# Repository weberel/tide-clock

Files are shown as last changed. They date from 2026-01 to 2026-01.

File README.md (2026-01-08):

# Tide Clock

A battery-powered e-paper display showing tide times. Configurable for any coastal location. This device does not need an internet or bluetooth connection as all data is calculated on the device itself from a given time and location. Thanks to the display type and slow refreshrate with long sleep cycles this device can operate on two AA-batteries for at least 3 years.

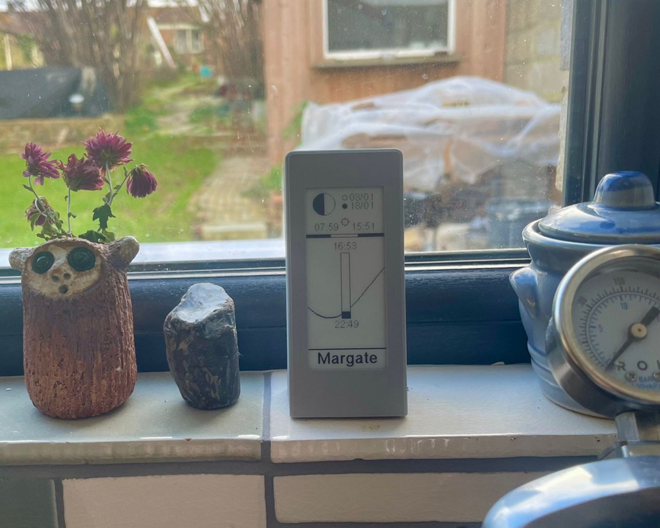
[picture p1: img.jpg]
Tide Clock


## Features

- **Tide prediction** - Next high/low tide times using a 31-constituent harmonic model
- **Moon phase** - Current phase with upcoming full/new moon dates
- **Sunrise/Sunset** - Daily times with 24-hour daylight visualization bar
- **Special messages** - Solstices, equinoxes, eclipses, meteor showers, holidays
- **Offline operation** - Pure mathematical models, no internet required
- **Multi-year battery life** - 15-minute wake cycles with deep sleep between updates

## Hardware

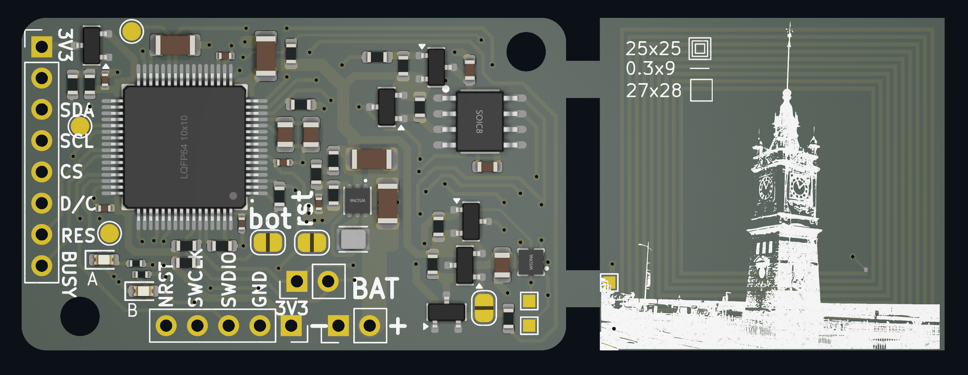
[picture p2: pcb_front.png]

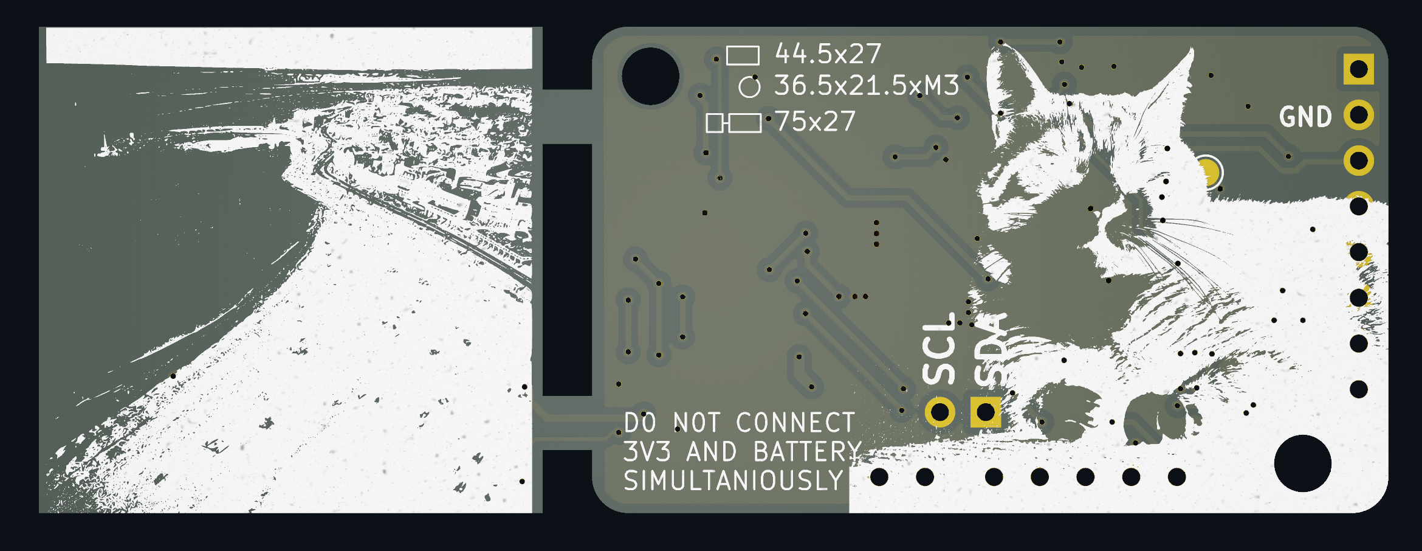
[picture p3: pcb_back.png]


- **MCU**: STM32F411RET6 (ARM Cortex-M4)
- **Display**: 2.9" e-paper (296x128, SSD1680 controller)
- **RTC**: DS3231MZ+ with alarm wake
- **Power**: AA batteries with TPS61099 boost converter

## Project Structure

```
tidal-clock/
├── firmware/          # STM32 firmware (Rev A & B)
├── simulator/         # SDL2 simulator for testing
├── scripts/           # Location config generation
│   └── harmonic_fitting/  # Tide model fitting
├── kicad/             # PCB designs
└── manual/            # User manual
```

Each folder has its own README with detailed instructions.

## Quick Start

### Simulator

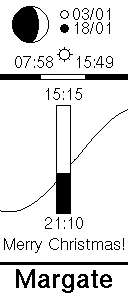
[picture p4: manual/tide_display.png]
Tide Display


```bash
cd simulator
sudo apt install libsdl2-dev
git clone https://github.com/olikraus/u8g2.git
make && ./tide_sim
```

### Firmware

```bash
cd firmware/revA  # or revB
cd lib && git clone https://github.com/olikraus/u8g2.git && cd ..
pio run --target upload
```

## Customizing Location

Configure for any coastal location. See [scripts/README.md](scripts/README.md) for details.

**US locations** (using NOAA API):
```bash
cd scripts
python3 generate_location.py --noaa 9414290 --name "San Francisco" --tz US_PACIFIC
```

**Other locations** (fit your own model):
```bash
python3 generate_location.py --json harmonic_fitting/model.json --name "Location" --tz UK
```

## License

MIT

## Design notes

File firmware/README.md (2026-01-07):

# Firmware

STM32 firmware for the tide clock. Two hardware revisions are supported.

## Building

```bash
# For Rev A hardware
cd revA
cd lib && git clone https://github.com/olikraus/u8g2.git && cd ..
pio run
pio run --target upload  # via ST-Link

# For Rev B hardware
cd revB
cd lib && git clone https://github.com/olikraus/u8g2.git && cd ..
pio run
pio run --target upload
```

## Configuration

Location settings are in `include/location_config.h`. Generate with:

```bash
cd scripts
python3 generate_location.py --noaa 9414290 --name "San Francisco" --tz US_PACIFIC
```

See the scripts README for more options.

## Hardware Differences

See [kicad/versions.md](../kicad/versions.md) for differences between Rev A and Rev B.

## Key Files

| File | Description |
|---|---|
| `src/main.c` | Entry point, power management |
| `src/tide.c` | Harmonic tide prediction |
| `src/astro.c` | Moon phase, sunrise/sunset |
| `src/timezone.c` | DST handling |
| `src/render.c` | Display layout |
| `include/location_config.h` | Location parameters (generated) |

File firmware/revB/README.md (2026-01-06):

# Tide Display - STM32 Hardware (Rev B)

E-paper tide display for Margate, UK using STM32F411CE and 2.9" SSD1680 tri-color display.

**This is the Rev B firmware.** See [firmware-revA](../firmware-revA/) for Rev A hardware.

## Hardware Changes (Rev B)

| Feature | Rev A | Rev B |
|---|---|---|
| NFC chip | NT3H2111 (unused) | ST25DV04K (for time sync) |
| Time setting | Button on PB1 | NFC (phone app) |
| PA2 function | NT3H2111 power gate | NFC LPD control |
| Button | PB1 (active LOW) | Removed |
| Wakeup | RTC alarm only | RTC alarm OR NFC field |
| External power | None | PB9 (3V3 gated output) |

## Features

- Current tide height with visual bar indicator
- Next high/low tide times (31-constituent harmonic model, ~5 min accuracy)
- Sunrise/sunset times with daylight bar
- Moon phase with next full/new moon dates
- Automatic BST/GMT timezone handling for UK
- 15-minute update cycle with deep sleep (~µA standby current)
- NFC time synchronization (planned)

## Operation

The device wakes from two sources:
1. **RTC alarm** (every 15 minutes) - normal display update
2. **NFC field** (phone tap) - time synchronization

Wake cycle:
1. PA0 rising edge wakes MCU from STOP mode
2. Determine wake source (check DS3231 alarm flag vs ST25DV field detect)
3. If NFC: read time sync data, update RTC if valid
4. If RTC alarm: update display
5. Set next alarm, enter STOP mode

## Building & Uploading

Requires PlatformIO.

```bash
# Build
pio run

# Upload via ST-Link
pio run --target upload
```

**Note:** If upload fails due to device in sleep mode, hold RESET while plugging in ST-Link, then release when upload starts.

## RTC Time Setting (Rev B)

Time is set via NFC:
1. Phone app writes time data to ST25DV user memory
2. Tapping phone to device wakes MCU via GPO → PA0
3. MCU reads time data, validates checksum
4. Updates DS3231 RTC
5. Display confirms sync (TODO)

See [kicad/versions.md](../../kicad/versions.md) for NFC time sync protocol details.

## Project Structure

```
firmware-revB/
├── src/
│   ├── main.c              # Entry point, RTC, NFC, sleep/wake cycle
│   ├── st25dv.c            # ST25DV04K NFC driver
│   ├── display_u8g2_stm32.c # Display HAL backend (SPI, GPIO)
│   ├── render.c            # UI rendering (layout, icons)
│   ├── tide.c              # Tide calculations (31-harmonic model)
│   ├── astro.c             # Sun/moon calculations (Meeus/NOAA)
│   └── timezone.c          # UK timezone handling (GMT/BST)
├── include/
│   ├── st25dv.h            # ST25DV04K driver header
│   └── *.h                 # Other headers
├── lib/
│   └── u8g2/               # u8g2 graphics library + custom SSD1680 driver
└── platformio.ini
```

## Pin Configuration (Rev B)

| Pin | Function |
|-----|---|
| PA0 | Wakeup (OR'd: RTC alarm + NFC field) |
| PA1 | DS3231 VCC gate (P-FET, active LOW) |
| PA2 | ST25DV LPD (HIGH = low power) |
| PA3 | Display VCC gate (P-FET, active LOW) |
| PB3 | Debug output (SWO) |
| PB6/PB7 | I2C1 (DS3231 + ST25DV) |
| PB9 | External 3V3 gate (P-FET, active LOW) |
| PC11 | LED2 |
| PD2 | LED1 |

## TODO

- [ ] Implement NFC time sync in main loop
- [ ] Add display confirmation after time sync
- [ ] Test wakeup from NFC field detection
- [ ] Implement external power control (PB9)

---

# Rendering System Report

## Overview

The rendering system produces a 128x296 pixel display showing tide, sun, and moon information for Margate, UK. The display is rotated 90 degrees for a portrait orientation.

## Display Layout

```
┌─────────────────────────────────────┐
│  ┌───┐                              │
│  │   │ Moon    ○ 15/01  (full)      │  Moon Section (y: 0-50)
│  │   │ Phase   ● 01/01  (new)       │
│  └───┘                              │
├─────────────────────────────────────┤
│           ☀ Sun Icon                │  Sun Section (y: 50-80)
│       06:45        18:30            │  Sunrise/Sunset times
│ ██████░░░░░░░░░░░░░░░░░░░░██████   │  Daylight bar
├─────────────────────────────────────┤
│                                     │
│  ~~~~      ┌───┐      ~~~~          │
│       ~~~~ │███│ ~~~~               │  Tide Section (y: 100-220)
│            │███│                    │  Sine wave + fill bar
│       ____ │   │ ____               │
│  ____      └───┘      ____          │
│            14:30                    │  Next high/low time
│                                     │
├─────────────────────────────────────┤
│ ═══════════════════════════════════ │  Separator line
│            MARGATE                  │  Location (y: 260-296)
└─────────────────────────────────────┘
```

## Rendering Pipeline

### 1. Data Collection

```c
// tide.c - 31-constituent harmonic model
float current_height = calculate_tide_height(target_time);
find_next_high_low(target_time, &next_high, &next_low);

// astro.c - Meeus/NOAA algorithms
float moon_phase = calculate_moon_phase(target_time);
find_next_full_new_moon(target_time, &next_full_moon, &next_new_moon);
calculate_sunrise_sunset(target_time, &sunrise_h, &sunrise_m, &sunset_h, &sunset_m);
```

### 2. Time Conversion

All internal calculations use UTC. Display times are converted to local Margate time (GMT/BST):

```c
// timezone.c - handles EU timezone rules
struct tm *local = utc_to_margate(utc_time);
int is_daylight = is_bst(utc_time);
```

### 3. UI Rendering (render.c)

#### Moon Phase Icon

- **Size:** 36px diameter (radius=18)
- **Position:** Top-left (cx=30, cy=24)
- **Algorithm:** Draws white circle, then overlays black shadow using terminator calculation

```c
// Waxing (phase 0-0.5): shadow on LEFT, terminator moves right
// Waning (phase 0.5-1): shadow on RIGHT, terminator moves left
for (int y = -radius; y <= radius; y++) {
    int x_extent = sqrt(radius² - y²);
    int terminator_x = cx + terminator * x_extent;
    // Draw shadow line from edge to terminator
}
```

#### Sun Icon

- **Size:** 10px diameter with 3px rays
- **Position:** Center-top (cx=64, cy=54)
- **8 rays** at 45-degree intervals

#### Daylight Bar

- **Full width:** 128px
- **Shows:** Night (black) / Day (white) proportions
- **Calculation:** `sunrise_frac = (hour + min/60) / 24`

#### Tide Display

- **Central bar:** 15x109px vertical fill gauge
- **Fill level:** Normalized between next low and high tide heights
- **Sine wave:** 6-hour window centered on current time

```c
// Phase calculation for sine wave
float tidal_period = 12.42;  // hours (M2 constituent)
float current_phase = asin(2 * normalized - 1);
if (!tide_rising) current_phase = PI - current_phase;

// Draw wave, skip over central bar region
for (int x = 0; x < DISPLAY_WIDTH; x++) {
    float phase = current_phase + (hours_offset / tidal_period) * 2*PI;
    int y = wave_center - sin(phase) * amplitude;
}
```

## Tide Calculation Model

### Harmonic Constituents (31 total)

| Constituent | Amplitude (m) | Period (hours) | Description |
|---|---|---|---|
| M2 | 1.6236 | 12.42 | Principal lunar |
| S2 | 0.4758 | 12.00 | Principal solar |
| N2 | 0.2846 | 12.66 | Larger lunar elliptic |
| K2 | 0.1624 | 11.97 | Lunisolar declinational |
| K1 | 0.1031 | 23.93 | Lunisolar diurnal |
| O1 | 0.1272 | 25.82 | Principal lunar diurnal |
| M4 | 0.0525 | 6.21 | Shallow water overtide |
| ... | ... | ... | (24 more) |

**Mean Sea Level:** 2.64m (Chart Datum)

### Empirical Time Correction

Accounts for nodal cycle (18.61 years) and seasonal variations:

```c
correction = nodal + annual + semiannual;
// nodal:     -4.4 * sin(2π/18.61 * (year - 2015.6)) + 0.45
// annual:    +1.7 * sin(2π * (year + 0.27))
// semiannual: +0.9 * sin(4π * (year + 0.12))
```

### Extremum Refinement

1. **Coarse search:** 15-minute samples over 24 hours (96 samples)
2. **Peak detection:** Find local maxima/minima
3. **Ternary search:** Refine to 30-second accuracy

## Astronomical Calculations

### Moon Phase (Meeus Algorithm)

- **Input:** Julian Date
- **Output:** Phase 0-1 (0=new, 0.5=full)
- **Accuracy:** ~1 minute for full/new moon times

### Sunrise/Sunset (NOAA Algorithm)

- **Location:** Margate (51.3813°N, 1.3862°E)
- **Zenith:** 90.833° (accounts for refraction)
- **Output:** Local time (with BST adjustment)

## Display Driver (SSD1680)

### Tri-color Handling

The SSD1680 is a BWR (black/white/red) display. To suppress red:

```c
// Write inverted data to BLACK RAM (0x24)
u8x8_cad_SendCmd(u8x8, 0x24);
u8x8_cad_SendData(u8x8, 8, ~tile_data);

// Write all zeros to COLOR RAM (0x26) at SAME offset
u8x8_cad_SendCmd(u8x8, 0x26);
u8x8_cad_SendData(u8x8, 8, zeros);
```

**Key insight:** Color RAM must be written with the same tile offset as black RAM, otherwise ghosting/red tint appears.

### Refresh Modes

Three refresh modes are available:

| Mode | Command | Time | Flashes | Use Case |
|---|---|---|---|---|
| Full (OTP) | 0xF7 | ~3s | Multiple | Best contrast, clears ghosting |
| Fast Full | 0xC7 | ~1s | Single | Regular updates, slight ghosting over time |
| Partial | 0x0F | ~0.3s | None | Small changes only, requires base image |

**Full Refresh (Original/Default)**
- Uses OTP (One-Time Programmable) waveform stored in display
- Multiple black-white-black flashes
- Best image quality and contrast
- Clears any accumulated ghosting
- Use: First boot, clearing ghosting (e.g., nightly)

**Fast Full Refresh (Recommended for regular updates)**
- Uses custom LUT (Look-Up Table) from Waveshare EPD_2IN9_V2_Init_Fast()
- Single flash (black → white → final image)
- Good contrast, ~3x faster than full refresh
- Slight ghosting accumulation over many updates
- Use: Regular 15-minute updates

**Partial Refresh**
- Uses custom partial LUT
- No flash, only changed pixels update
- Fastest but lowest contrast
- Requires base image in both RAM banks
- Use: Not recommended for this display (poor results)

### Refresh Mode API

```c
// Set refresh mode before calling display_update()
display_set_full_mode();       // OTP waveform, multiple flashes (~3s)
display_set_fast_full_mode();  // Custom LUT, single flash (~1s)
display_set_partial_mode();    // Partial update (~0.3s)

// Example usage
display_set_fast_full_mode();
display_clear();
render_tide_display(current_time, message);
display_update(NULL);
```

### BUSY Pin Handling

The BUSY pin (PA9) indicates display refresh status:
- **HIGH** = Display is busy (refreshing)
- **LOW** = Display is ready

Wait sequence after sending refresh command:
```c
// Wait for BUSY to go HIGH (refresh started)
while (HAL_GPIO_ReadPin(GPIOA, GPIO_PIN_9) == GPIO_PIN_RESET) {
    // timeout after 500ms
}

// Wait for BUSY to go LOW (refresh complete)
while (HAL_GPIO_ReadPin(GPIOA, GPIO_PIN_9) == GPIO_PIN_SET) {
    __WFI();  // Light sleep, wake on SysTick (1ms)
}
```

### Production Refresh Strategy

For battery-powered operation with ~15 min update intervals:
- Use `display_set_fast_full_mode()` for all regular updates
- Do one `display_set_full_mode()` update per night (e.g., 3am) to clear ghosting

```c
// In main update loop
if (local->tm_hour == 3 && local->tm_min < 15) {
    display_set_full_mode();  // Nightly full refresh
} else {
    display_set_fast_full_mode();  // Fast refresh
}
```

## Power Optimization

### During Display Refresh

```c
// Use __WFI() for light sleep while polling BUSY
while (HAL_GPIO_ReadPin(EPD_PORT, EPD_BUSY_PIN) == GPIO_PIN_SET) {
    __WFI();  // Wake every 1ms on SysTick
}
```

### Between Updates

- **STOP mode:** ~uA current
- **Wake source:** EXTI0 (DS3231 alarm via P-FET)
- **Cycle time:** 15 minutes

## Memory Usage

```
RAM:    5,776 bytes (4.4% of 128KB)
Flash: 75,780 bytes (14.5% of 512KB)
```

Breakdown:
- u8g2 framebuffer: ~5KB (128x296/8 = 4,736 bytes)
- Tide constituents: ~400 bytes (31 × 12 bytes)
- Stack/heap: ~600 bytes

---

# Hardware Test Documentation

PlatformIO project using STM32Cube HAL framework.

## Completed Tests (HAL)

### E-Paper Display (SSD1680 296x128 BWR)
- Full refresh working with WeAct 2.9" display
- X RAM address offset: 1-16 (WeAct specific)
- BWR displays don't support fast partial refresh

### DS3231 RTC
- I2C communication working (address 0x68)
- Time set/get working
- Alarm1 working (hour:min:sec match)

### Sleep/Wakeup Cycle
- STOP mode working (deep sleep, LEDs off)
- Wake via PA0 (DS3231 INT through P-FET -> rising edge)
- PA0 state detection on boot to distinguish fresh boot vs alarm wakeup
- Alarm flags cleared after wakeup

### Button Time Setting
- Button on PA2 for user input
- Hold on boot to enter time-setting mode
- Short presses cycle through hours/minutes

---

## Pin Configuration

| Pin  | Function |
|---|---|
| PA0  | Wakeup (DS3231 INT via MOSFET) |
| PA1  | Gate: DS3231 VCC P-FET (LOW=ON) |
| PA2  | Button input (active LOW) |
| PA3  | Gate: Display VCC P-FET (LOW=ON)  |
| PA4  | Display CS |
| PA5  | Display CLK |
| PA6  | Display DC |
| PA7  | Display DIN |
| PA8  | Display RST |
| PA9  | Display BUSY |
| PA10 | DS3231 RST (power status input) |
| PB6  | I2C1 SCL (DS3231) |
| PB7  | I2C1 SDA |
| PC11 | LED2 (active HIGH) |
| PC14 | DS3231 32kHz out (LSE input) |
| PD2  | LED1 (active HIGH) |

## ST-Link Connection

```
ST-Link    STM32F411
-------    ---------
SWDIO  --> PA13
SWCLK  --> PA14
GND    --> GND
3.3V   --> 3V3 (optional)
NRST   --> NRST (optional, helps recovery)
```

## Troubleshooting

**Can't upload:**
- Check ST-Link connections (SWDIO, SWCLK, GND)
- Try holding RESET while starting upload
- Check if BOOT0 is LOW (should be for normal boot)

**Display shows red tint:**
- Ensure color RAM (0x26) is written with zeros at same offset as black RAM
- Check tile-by-tile writing includes color RAM

**Device not waking from sleep:**
- Check DS3231 alarm flags are cleared before sleep
- Verify EXTI is configured for rising edge (P-FET inverts INT signal)
- Ensure PA0 has pull-down resistor

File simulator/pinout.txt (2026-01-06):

PA0: DS3231 INT (over mosefet), NT3H2111 FD (over mosfet)
PA1: Gate pin for VCC mosfet of ds3231
PA2: Gate pin for VCC mosfet of NT3H2111
PA3: Gate pin for VCC mosfet of Display
PA4: Display CS
PA5: Display CLK
PA6: Display DC
PA7: Display DIN
PA8: Display RST
PA9: Display Busy
PA10: DS3231 RST
PA11: NC
PA12: Test Point
PA13: St-link connection
PA14: st-lin connection
PB1: Test Point
PB2-5: NC
PB6: SCL (ds3231, nt3h2111)
PB7: SDA
PB8-14: NC
PB15: Testpoint
PC0-5: NC
PC6-7: Test Point
PC8-10:NC
PC11: LED
PC12: NC
PC13: NC
PC14: DS3231 osc out
PC15: NC
PD2: LED

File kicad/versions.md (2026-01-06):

# Hardware Versions

## Rev A (Tested)

First production version. Fully tested and working.

### Key ICs

| Component | Part Number | Function |
|---|---|---|
| MCU | STM32F411RET6 | ARM Cortex-M4, 512KB flash, 128KB RAM |
| RTC | DS3231MZ+ | Real-time clock with temperature-compensated crystal |
| Boost Converter | TPS61099DRVR | 3.3V output from AA batteries |
| NFC | NT3H2111 | NFC tag IC (not used in firmware) |
| P-FET | AO3401A | Power gating for display and RTC VCC |
| N-FET | AO3400A | Signal level shifting |

### Features
- 2.9" e-paper display (SSD1680 controller)
- Button for time setting (active LOW)
- AA battery power
- Deep sleep with RTC alarm wake

### Pin Configuration
| Pin | Function |
|-----|---|
| PA0 | Wakeup (DS3231 INT via P-FET inverter) |
| PA1 | DS3231 VCC gate (P-FET, active LOW) |
| PA2 | NT3H2111 VCC gate (P-FET, active LOW, unused) |
| PA3 | Display VCC gate (P-FET, active LOW) |
| PB1 | Button input (active LOW) |
| PB6/PB7 | I2C1 (DS3231) |
| PC11 | LED2 |
| PD2 | LED1 |

---

## Rev B (Not Yet Tested)

Improved version with NFC time setting and external power output.

### Key ICs

| Component | Part Number | Function |
|---|---|---|
| MCU | STM32F411RET6 | ARM Cortex-M4, 512KB flash, 128KB RAM |
| RTC | DS3231MZ+ | Real-time clock with temperature-compensated crystal |
| Boost Converter | TPS61099DRVR | 3.3V output from AA batteries |
| NFC | ST25DV04K-JFR6D3 | Dynamic NFC tag with I2C interface |
| P-FET | AO3401A | Power gating |
| N-FET | AO3400A | Signal level shifting |

### Changes from Rev A

| Change | Rev A | Rev B |
|---|---|---|
| NFC chip | NT3H2111 (unused) | ST25DV04K (active) |
| Time setting | Button (PB1) | NFC (phone writes time) |
| PA2 function | NT3H2111 power gate | NFC LPD (Low Power Down) |
| Button | PB1 (active LOW) | Removed |
| Wakeup source | RTC alarm only | RTC alarm OR NFC field detect |
| External power | None | PB9 (3V3 output with P-FET gate) |
| DS3231 RST pullup | Present (parasitic) | Removed |
| ST-Link debug | Basic | Debug pin exposed (PB3/SWO) |

### Wakeup Circuit (Rev B)

PA0 receives OR'd signal from two sources:
1. **DS3231 alarm**: INT pin (active LOW) → P-FET inverter → HIGH
2. **ST25DV GPO**: CMOS output → HIGH when RF field detected

Both signals go through Schottky diodes for OR-ing, with PA0 pulled LOW.
Rising edge on PA0 wakes MCU from STOP mode.

### Pin Configuration
| Pin | Function |
|-----|---|
| PA0 | Wakeup (OR'd: RTC alarm + NFC field detect) |
| PA1 | DS3231 VCC gate (P-FET, active LOW) |
| PA2 | ST25DV LPD (HIGH = low power, LOW = active) |
| PA3 | Display VCC gate (P-FET, active LOW) |
| PB3 | Debug output (SWO) |
| PB6/PB7 | I2C1 (DS3231 + ST25DV) |
| PB9 | External 3V3 gate (P-FET, active LOW) |
| PC11 | LED2 |
| PD2 | LED1 |

### NFC Time Sync Protocol

Phone app writes 8 bytes to ST25DV user memory at offset 0x0010:

| Byte | Content |
|---|---|
| 0 | Year - 2000 |
| 1 | Month (1-12) |
| 2 | Day (1-31) |
| 3 | Hour (0-23) |
| 4 | Minute (0-59) |
| 5 | Second (0-59) |
| 6 | Checksum (XOR of bytes 0-5) |
| 7 | Magic (0xA5 = valid) |

When NFC field is detected:
1. MCU wakes via GPO → PA0
2. Reads time sync data from ST25DV
3. If valid (magic + checksum), updates DS3231 RTC
4. Clears magic byte to prevent re-reading
5. Optionally updates display to confirm sync

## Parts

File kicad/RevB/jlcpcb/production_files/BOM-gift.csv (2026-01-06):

Comment | Designator | Footprint | LCSC | Quantity
100kΩ | R1,R13,R14,R16,R17,R3,R7,R8 | R_0603 | C25803 | 8
100nF | C1,C14 | C_0603 | C14663 | 2
100nF | C10,C3,C4,C5,C6 | C_0402 | C1525 | 5
100nF | C8 | C_0805 | C28233 | 1
100pF | C11 | C_0402 | C1546 | 1
10kΩ | R18,R20 | R_0402 | C25744 | 2
10kΩ | R10,R6,R9 | R_0603 | C25804 | 3
10uF | C12,C13 | C_1206 | C13585 | 2
1MΩ | R11 | R_0603 | C22935 | 1
1kΩ | R12,R2,R5 | R_0603 | C21190 | 3
1uF | C7 | C_0805 | C28323 | 1
220nF | C2 | C_0805 | C5378 | 1
4.7uF | C15,C9 | C_1206 | C29823 | 2
470kΩ | R15 | R_0603 | C23178 | 1
47kΩ | R4 | R_0603 | C25819 | 1
AO3400A | Q5 | Q_SOT-23 | C20917 | 1
AO3401A | Q1,Q2,Q3,Q4,Q6 | Q_SOT-23 | C15127 | 5
DS3231MZ+ | U2 | SOIC-8_L4.9-W3.9-P1.27-LS6.0-BL | C107410 | 1
NT3H2111W0FHKH | U4 | XQFN-8_L1.6-W1.6-P0.50-BL_NT3H2111W0FHKH | C710403 | 1
Red | D1,D2 | D_0603 | C2286 | 2
STM32F411RET6 | U6 | LQFP-64_L10.0-W10.0-P0.50-LS12.0-BL | C94355 | 1
TPS61099DRVR | U3 | WSON-6_L2.0-W2.0-P0.65-TL-EP | C2842395 | 1
VLS201610CX-2R2M-1 | U1 | IND-SMD_L2.0-W1.6 | C2041554 | 1

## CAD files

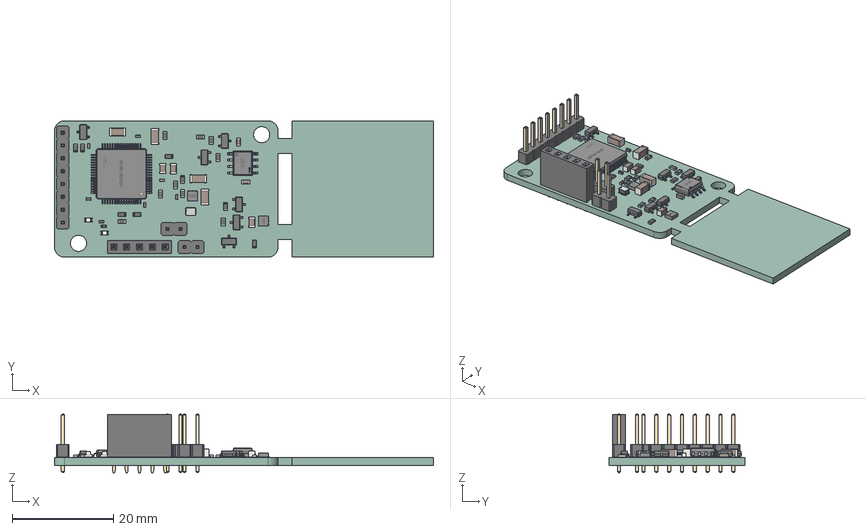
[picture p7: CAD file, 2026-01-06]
kicad/RevB/tidal-clock.step
75.0 x 27.0 x 11.6 mm
C_0805 x 3
R_0603 x 17
SOIC-8_L4.9-W3.9-H1.7-LS6.0-P1.27
C_0402 x 6
Q_SOT-23 x 6
C_0603 x 2
PinHeader_1x02_P2.54mm_Vertical x 2
WSON-6_L2.0-W2.0-H0.8-P0.65 x 2
PinHeader_1x08_P2.54mm_Vertical
C_1206 x 4
D_0603 x 2
LQFP-64_L10.0-W10.0-H1.4-LS12.0-P0.50
IND-SMD_L2.0-W1.6-H1.1
PinSocket_1x05_P2.54mm_Vertical
R_0402 x 2
gift_PCB

simulator/u8g2/sys/arduino/u8g2_full_buffer/SwitchBox/board.dxf
60
40
52
8
24
80
30
32
25
100
190
4
12
6
14

simulator/u8g2/sys/arm/stm32l031x6/clock_2.dxf
65
Draufsicht
Vorderansicht
von unten
von rechts
von links
14
30
32
35
75
55
10
12
16
11
22
34
28
29
18
93
19
43
15
68
60
57
150
Holzbohrer: 2.5, 8, 10, 12, 16, 32mm
8
7
6
2.5mm

simulator/u8g2/sys/arm/stm32l031x6/clock.dxf
65
32
28
16
Draufsicht
Vorderansicht
von unten
von rechts
von links
14
6
45
60
30
20
8
35
75
55
10
12

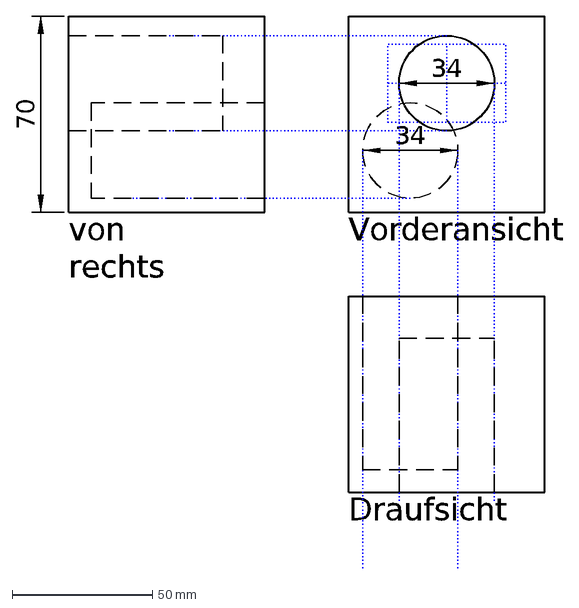
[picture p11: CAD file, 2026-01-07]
simulator/u8g2/sys/arm/stm32l031x6/clock_cube.dxf
Draufsicht
Vorderansicht
von rechts
70
34

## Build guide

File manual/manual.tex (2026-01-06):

\documentclass[a5paper,8pt]{article}
\usepackage[utf8]{inputenc}
\usepackage[T1]{fontenc}
\usepackage{tgheros}
\renewcommand{\familydefault}{\sfdefault}
\usepackage[top=0.5cm,bottom=0cm,left=0.5cm,right=0.5cm]{geometry}
\usepackage{graphicx}
\usepackage{multicol}
\usepackage{parskip}
\usepackage{titlesec}

\setlength{\parskip}{0.15em}
\setlength{\columnsep}{0.4cm}
\titleformat{\subsection}{\normalfont\small\bfseries}{\thesubsection}{0.3em}{}
\titlespacing*{\subsection}{0pt}{0.3em}{0.05em}
\pagestyle{empty}

\begin{document}

\begin{center}
{\large\bfseries Tide Display - Manual}
\end{center}

\vspace{0.1em}

\begin{multicols}{2}
\footnotesize

\noindent This is a tidal display, relying on mathematical models for all of its predictions, allowing the device to operate offline. Not needing wireless connections and employing a low refreshrate e-paper display, the device is capable of running for 2+ years with AA batteries.

\subsection*{1. Moon Phase Display}
The current moon phase is calculated via the Meeus algorithm, which uses the 29.53-day lunar cycle and applies 15 periodic corrections for the gravitational pull of the sun, the moon's elliptical orbit, and other astronomical factors. It is accurate to within 1\% indefinitely.

\subsection*{2. Next Full and New Moon Dates}
Using the same mathematical model, the next full and new moon dates are calculated. The predictions are accurate to within 2 minutes indefinitely.

\subsection*{3. Sunrise and Sunset Times}
Based on another equation derived by Jean Meeus, the model takes into account the Earth's elliptical orbit and axial tilt to determine sunrise and sunset times for a given latitude. The algorithm predicts within an error of 2 minutes. Local phenomena such as geographical features or tall buildings are not taken into account.

\subsection*{4. Daily Daylight Display}
Using the sunrise and sunset times, the bar represents a 24-hour cycle starting at midnight. Dark sections indicate night; light sections indicate daylight.

\subsection*{5. Tidal Display}
Unlike conventional tidal clocks that simply show a 12-hour 25-minute cycle, this tidal display is based on a harmonic model taking into account 31 periodic phenomena. The most influential are the orbits of the sun and moon; other factors include local effects such as shallow water and the Thames estuary. As the mathematical models needed for tide predictions are not freely available, a model was derived using historic tidal data and predictions from the Port of London Authority. The model achieves 10--15 minute accuracy for most days. Predictions will likely remain accurate over the next 25 years; however, changes in sea level and long-period astronomical effects may reduce accuracy in the distant future. Weather effects are not taken into account.

\subsection*{6. Daily Message}
Shows important events including summer and winter solstices, equinoxes, solar and lunar eclipses visible from Margate over the next 100 years, and the six most prominent recurring meteor showers.

\subsection*{7. Location}
Shows the location for which this display is calibrated. The sunrise, sunset, and tidal calculations are specific to this geographical location.

\end{multicols}

\vfill

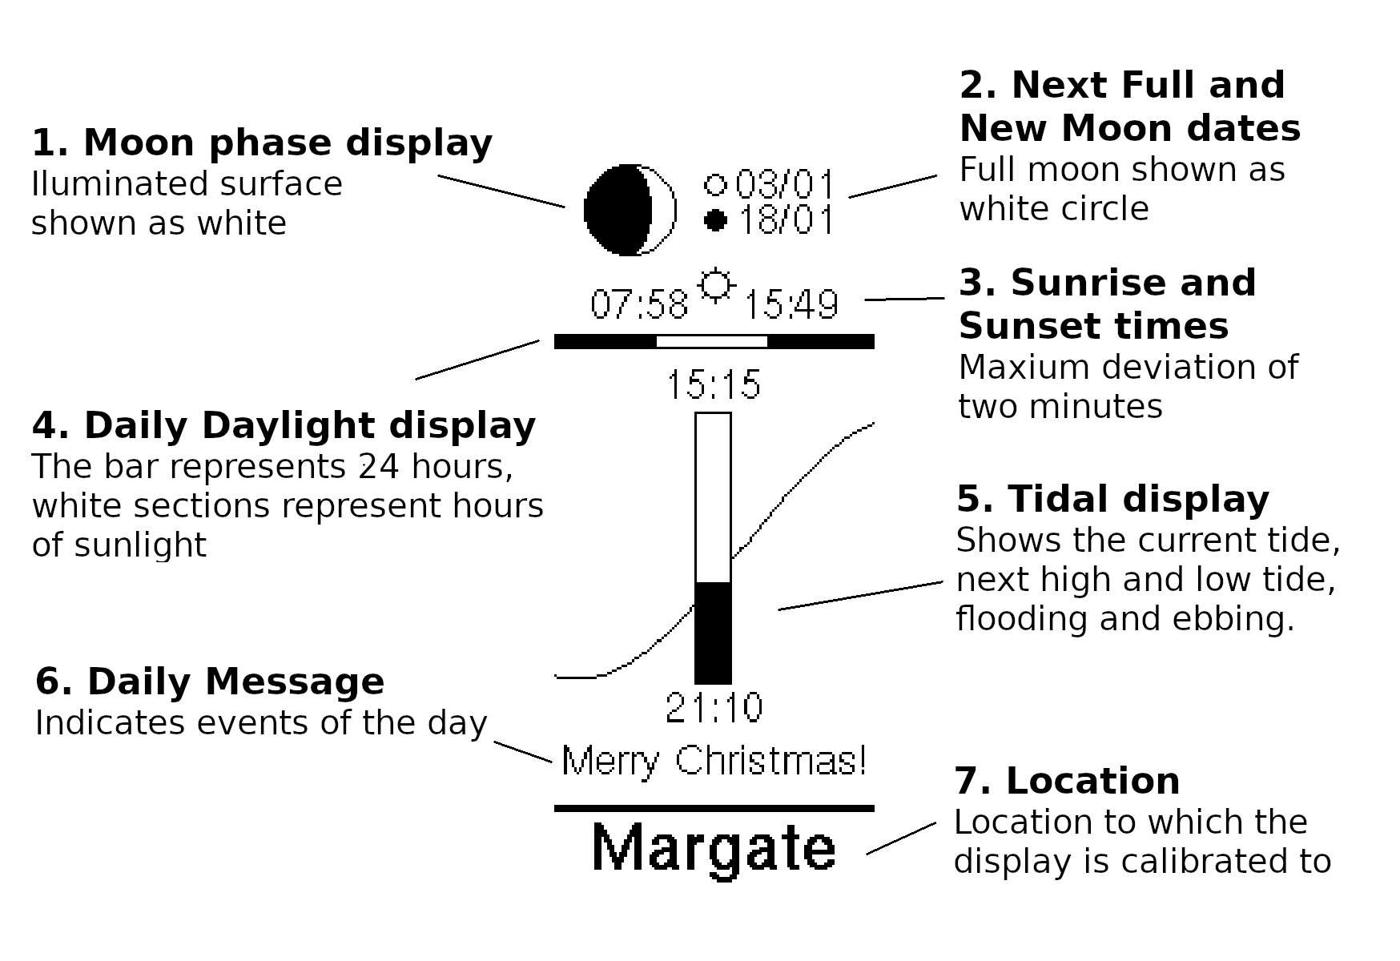
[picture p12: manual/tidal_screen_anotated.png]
\noindent

\end{document}

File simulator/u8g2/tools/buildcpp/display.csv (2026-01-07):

# 1. device name
# 2. pinset
# 3. constructor name w/o prefix
u8x8_d_ssd1306_128x64_noname | 4WSWSPI | SSD1306_128X64_4W_SW_SPI
u8x8_d_ssd1306_128x64_noname | 4WHWSPI | SSD1306_128X64_4W_HW_SPI
u8x8_d_ssd1306_128x64_noname | 3WSWSPI | SSD1306_128X64_3W_SW_SPI
u8x8_d_ssd1306_128x64_noname | SSDSWI2C | SSD1306_128X64_SW_I2C
u8x8_d_ssd1306_128x64_noname | 6800 | SSD1306_128X64_6800
u8x8_d_ssd1306_128x64_noname | 8080 | SSD1306_128X64_8080

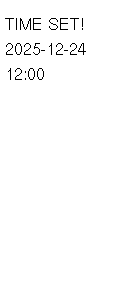
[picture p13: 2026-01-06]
manual/screen_confirmed.png

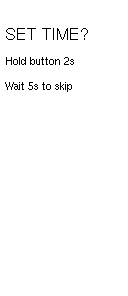
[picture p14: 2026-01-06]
manual/screen_timeset.png

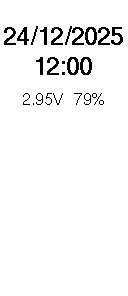
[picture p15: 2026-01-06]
manual/screen_boot.png

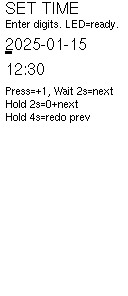
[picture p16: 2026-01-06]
manual/screen_timeset_entry.png

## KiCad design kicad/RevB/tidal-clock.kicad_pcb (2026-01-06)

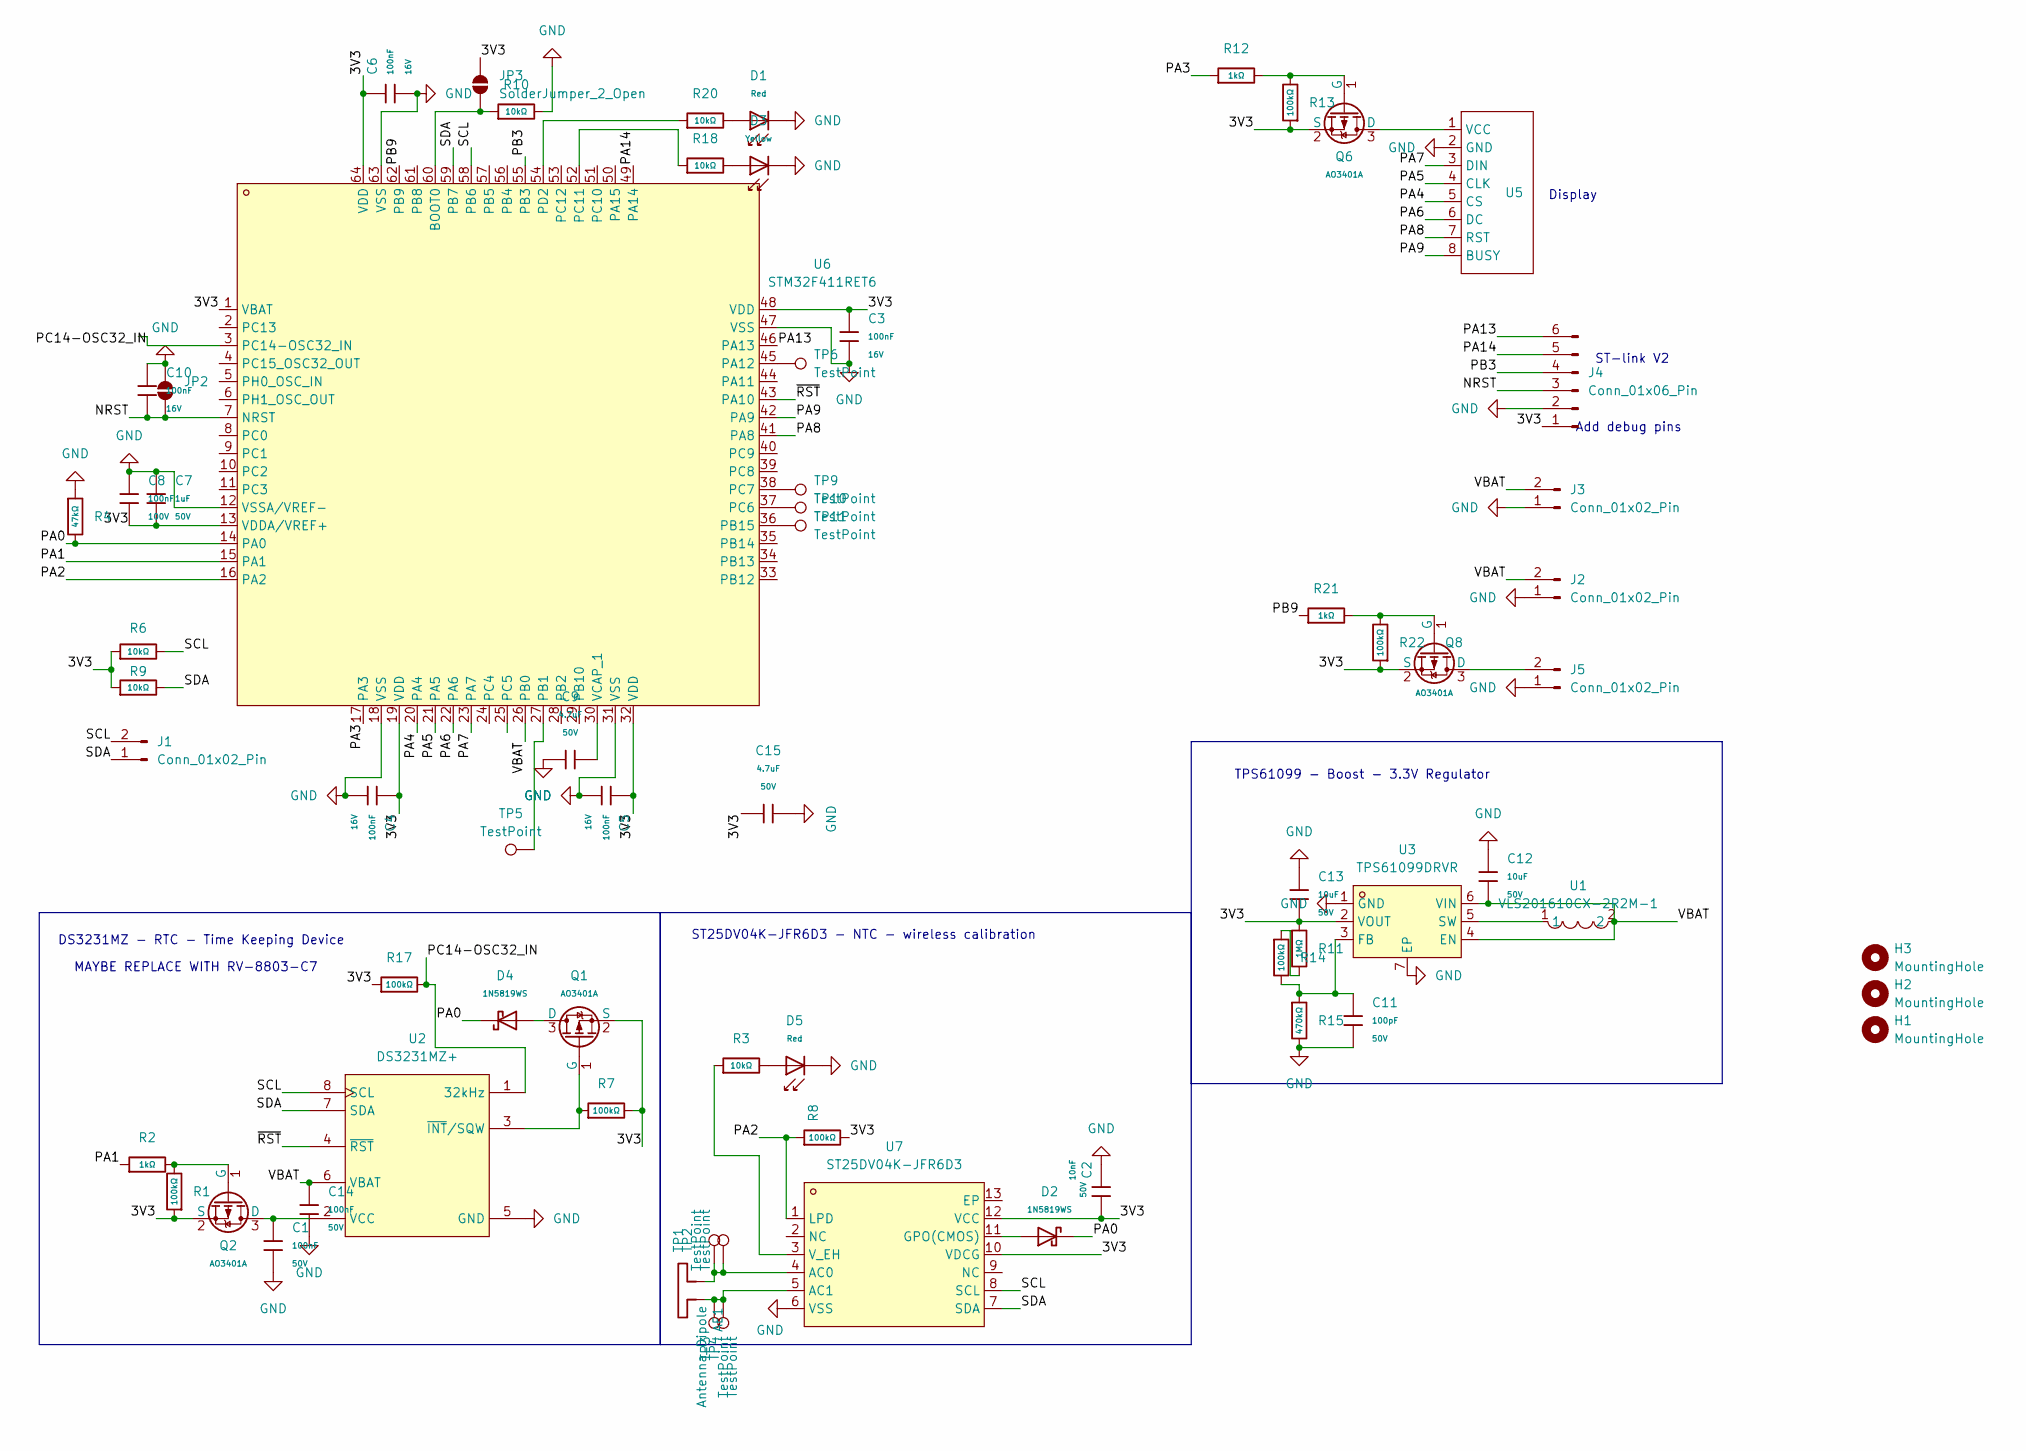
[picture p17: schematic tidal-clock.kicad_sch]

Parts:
AE1: Antenna_Dipole; NFC_COIL
C1, C14: 100nF; C_0603; Voltage Rated 50V; Tolerance ±10%; Part CC0603KRX7R9BB104; LCSC C14663
C2: 10nF; C_0402; Voltage Rated 50V; Tolerance ±10%; Part CL05B103KB5NNNC; LCSC C15195
C3, C4, C5, C6, C10: 100nF; C_0402; Voltage Rated 16V; Tolerance ±10%; Part CL05B104KO5NNNC; LCSC C1525
C7: 1uF; C_0805; Voltage Rated 50V; Tolerance ±10%; Part CL21B105KBFNNNE; LCSC C28323
C8: 100nF; C_0805; Voltage Rated 100V; Tolerance ±10%; Part CL21B104KCFNNNE; LCSC C28233
C9, C15: 4.7uF; C_1206; Voltage Rated 50V; Tolerance ±10%; Part 1206B475K500NT; LCSC C29823
C11: 100pF; C_0402; Voltage Rated 50V; Tolerance ±5%; Part 0402CG101J500NT; LCSC C1546
C12, C13: 10uF; C_1206; Voltage Rated 50V; Tolerance ±10%; Part CL31A106KBHNNNE; LCSC C13585
D1, D5: Red; D_0603; Part KT-0603R; LCSC C2286
D2, D4: 1N5819WS; D_SOD-323; Forward Voltage (Vf@If) 600mV@1A; Reverse Voltage (Vr) 40V; Part 1N5819WS; LCSC C191023
D3: Yellow; D_0603; Forward Voltage (VF) 1.6V~2.6V; Part NCD0603Y2; LCSC C89811
H1, H2, H3: MountingHole; MountingHole_2.2mm_M2_ISO14580
J1, J2, J3, J5: Conn_01x02_Pin; PinHeader_1x02_P2.54mm_Vertical
J4: Conn_01x06_Pin; PinSocket_1x06_P2.54mm_Vertical
JP2, JP3: SolderJumper_2_Open; SolderJumper-2_P1.3mm_Open_RoundedPad1.0x1.5mm
Q1, Q2, Q6, Q8: AO3401A; Q_SOT-23; Part AO3401A; LCSC C15127
R1, R7, R8, R13, R14, R17, R22: 100kΩ; R_0603; Overload Voltage (Max) 75V; Tolerance ±1%; Part 0603WAF1003T5E; LCSC C25803
R2, R12, R21: 1kΩ; R_0603; Overload Voltage (Max) 75V; Tolerance ±1%; Part 0603WAF1001T5E; LCSC C21190
R3, R18, R20: 10kΩ; R_0402; Overload Voltage (Max) 50V; Tolerance ±1%; Part 0402WGF1002TCE; LCSC C25744
R4: 47kΩ; R_0603; Overload Voltage (Max) 75V; Tolerance ±1%; Part 0603WAF4702T5E; LCSC C25819
R6, R9, R10: 10kΩ; R_0603; Overload Voltage (Max) 75V; Tolerance ±1%; Part 0603WAF1002T5E; LCSC C25804
R11: 1MΩ; R_0603; Overload Voltage (Max) 75V; Tolerance ±1%; Part 0603WAF1004T5E; LCSC C22935
R15: 470kΩ; R_0603; Overload Voltage (Max) 75V; Tolerance ±1%; Part 0603WAF4703T5E; LCSC C23178
TP1, TP2, TP3, TP4: TestPoint; TestPoint_Pad_1.0x1.0mm
TP5, TP6, TP9, TP10, TP11: TestPoint; TestPoint_Pad_D1.5mm
U1: VLS201610CX-2R2M-1; IND-SMD_L2.0-W1.6; LCSC Part C2041554
U2: DS3231MZ+; SOIC-8_L4.9-W3.9-P1.27-LS6.0-BL; LCSC Part C107410
U3: TPS61099DRVR; WSON-6_L2.0-W2.0-P0.65-TL-EP; LCSC Part C2842395
U5: PinHeader_1x08_P2.54mm_Vertical
U6: STM32F411RET6; LQFP-64_L10.0-W10.0-P0.50-LS12.0-BL; LCSC Part C94355
U7: ST25DV04K-JFR6D3; UDFN-12_L3.0-W3.0-P0.50-TR-EP; LCSC Part C2654815

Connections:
/3V3: C2.1, C3.1, C4.1, C5.1, C6.1, C7.2, C8.2, C13.2, C15.1, J4.1, JP3.2 (B), Q1.2 (S), Q2.2 (S), Q6.2 (S), Q8.2 (S), R1.1, R6.1, R7.2, R8.2, R9.1, R11.1, R13.1, R17.1, R22.1, U3.2 (VOUT), U6.1 (VBAT), U6.13 (VDDA/VREF+), U6.19 (VDD), U6.32 (VDD), U6.48 (VDD), U6.64 (VDD), U7.10 (VDCG), U7.12 (VCC)
/NRST: C10.2, J4.3, JP2.1 (A), U6.7 (NRST)
/PA0: D2.1, D4.1, R4.2, U6.14 (PA0)
/PA1: R2.1, U6.15 (PA1)
/PA2: R8.1, U6.16 (PA2), U7.1 (LPD)
/PA3: R12.1, U6.17 (PA3)
/PA4: U5.5 (CS), U6.20 (PA4)
/PA5: U5.4 (CLK), U6.21 (PA5)
/PA6: U5.6 (DC), U6.22 (PA6)
/PA7: U5.3 (DIN), U6.23 (PA7)
/PA8: U5.7 (RST), U6.41 (PA8)
/PA9: U5.8 (BUSY), U6.42 (PA9)
/PA13: J4.6, U6.46 (PA13)
/PA14: J4.5, U6.49 (PA14)
/PB3: J4.4, U6.55 (PB3)
/PB9: R21.1, U6.62 (PB9)
/PC14-OSC32_IN: R17.2, U2.1 (32kHz), U6.3 (PC14-OSC32_IN)
/SCL: J1.2, R6.2, U2.8 (SCL), U6.58 (PB6), U7.8 (SCL)
/SDA: J1.1, R9.2, U2.7 (SDA), U6.59 (PB7), U7.7 (SDA)
/VBAT: C12.2, C14.1, J2.2, J3.2, U1.2, U2.6 (VBAT), U3.4 (EN), U3.6 (VIN), U6.26 (PB0)
/~RST: U2.4 (~RST), U6.43 (PA10)
GND: C1.2, C2.2, C3.2, C4.2, C5.2, C6.2, C7.1, C8.1, C9.1, C10.1, C11.2, C12.1, C13.1, C14.2, C15.2, D1.1, D3.1, D5.1, J2.1, J3.1, J4.2, J5.1, JP2.2 (B), R4.1, R10.2, R15.2, U2.5 (GND), U3.1 (GND), U3.7 (EP), U5.2 (GND), U6.12 (VSSA/VREF-), U6.18 (VSS), U6.31 (VSS), U6.47 (VSS), U6.63 (VSS), U7.6 (VSS)
unnamed: D1.2, R20.2
unnamed: D3.2, R18.2
unnamed: D5.2, R3.2
unnamed: J5.2, Q8.3 (D)
unnamed: JP3.1 (A), R10.1, U6.60 (BOOT0)
unnamed: D4.2, Q1.3 (D)
unnamed: Q1.1 (G), R7.1, U2.3 (~INT/SQW)
unnamed: C1.1, Q2.3 (D), U2.2 (VCC)
unnamed: Q2.1 (G), R1.2, R2.2
unnamed: Q6.3 (D), U5.1 (VCC)
unnamed: Q6.1 (G), R12.2, R13.2
unnamed: Q8.1 (G), R21.2, R22.2
unnamed: R11.2, R14.1
unnamed: C11.1, R14.2, R15.1, U3.3 (FB)
unnamed: U1.1, U3.5 (SW)
unnamed: TP6.1, U6.45 (PA12)
unnamed: TP5.1, U6.27 (PB1)
unnamed: TP11.1, U6.36 (PB15)
unnamed: TP10.1, U6.37 (PC6)
unnamed: TP9.1, U6.38 (PC7)
unnamed: R18.1, U6.52 (PC11)
unnamed: R20.1, U6.54 (PD2)
unnamed: C9.2, U6.30 (VCAP_1)
unnamed: AE1.1, TP1.1, TP2.1, U7.4 (AC0)
unnamed: AE1.2, TP3.1, TP4.1, U7.5 (AC1)
unnamed: D2.2, U7.11 (GPO(CMOS))
unnamed: R3.1, U7.3 (V_EH)

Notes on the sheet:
Add debug pins
TPS61099 - Boost - 3.3V Regulator
ST-link V2
DS3231MZ - RTC - Time Keeping Device
MAYBE REPLACE WITH RV-8803-C7
Display
ST25DV04K-JFR6D3 - NTC - wireless calibration

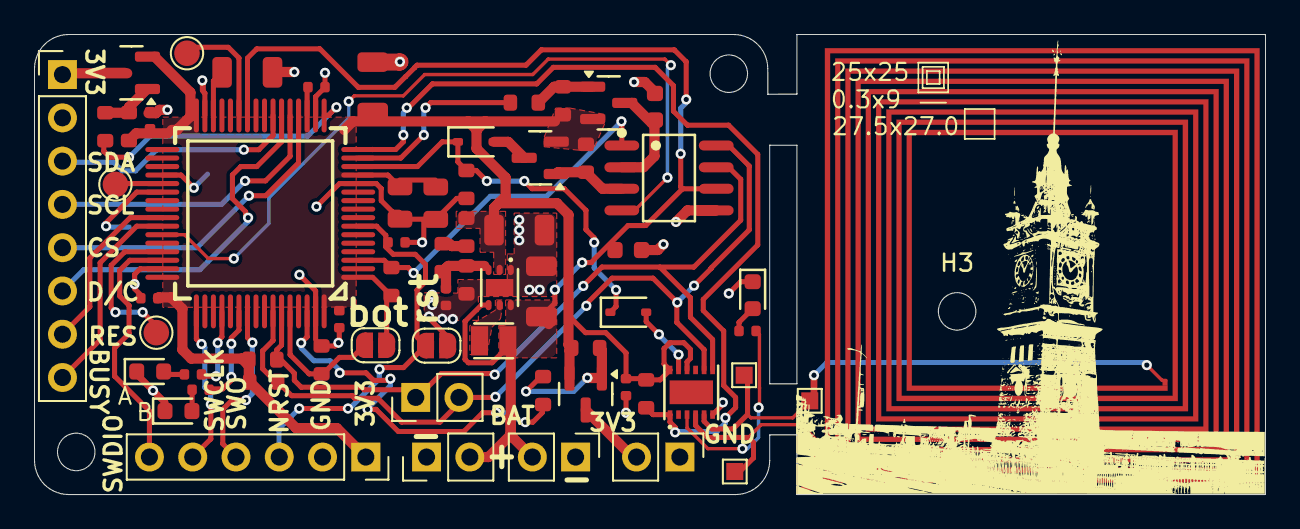
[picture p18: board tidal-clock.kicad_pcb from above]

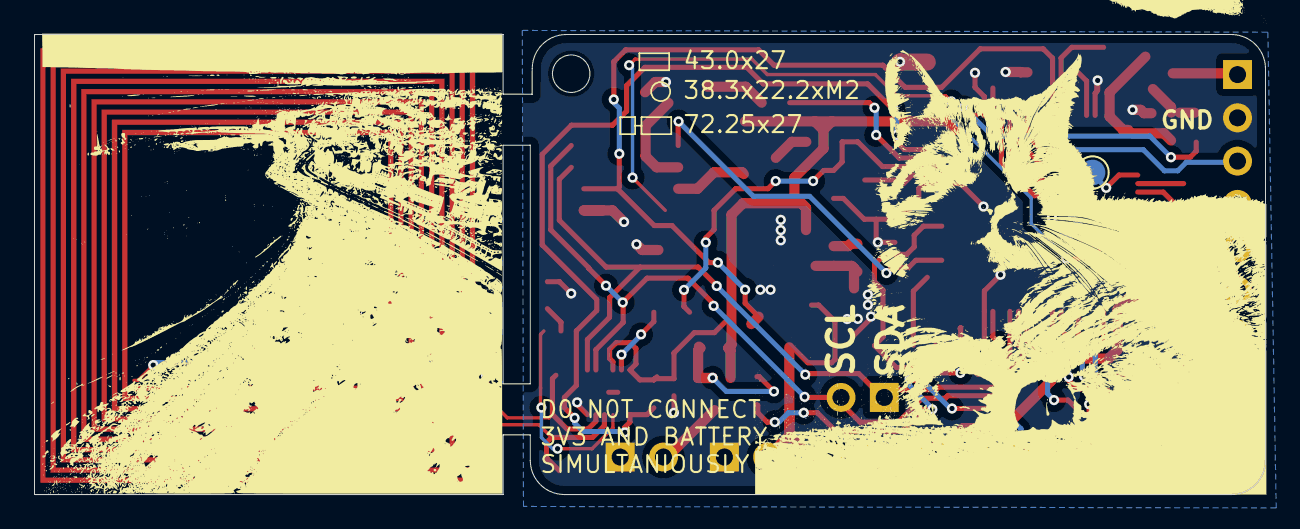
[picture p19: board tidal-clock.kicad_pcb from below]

Board: 2 copper layers, 72.2 x 27.0 mm, 69 parts (2 on the bottom side), 49 nets.

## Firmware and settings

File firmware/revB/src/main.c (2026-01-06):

/**
 * Tide Display - STM32 Main Entry Point (Rev B)
 *
 * Hardware changes from Rev A:
 * - ST25DV04K NFC instead of NT3H2111
 * - PA2 now NFC LPD (Low Power Down) instead of power gate
 * - PA0 wakeup via OR diode: DS3231 alarm (via MOSFET) OR ST25DV GPO (direct)
 * - PB9 external 3V3 power gate
 * - Removed parasitic pullup on DS3231 RST
 * - Button removed (time set via NFC)
 *
 * Wake cycle:
 * 1. Wake from STOP mode (PA0 rising edge from RTC alarm OR NFC field)
 * 2. Determine wake source (RTC alarm vs NFC field)
 * 3. If NFC: check for time sync data, update RTC if valid
 * 4. If RTC alarm: normal display update cycle
 * 5. Set next alarm, enter STOP mode
 */

#include "stm32f4xx_hal.h"
#include "display.h"
#include "render.h"
#include "tide.h"
#include "astro.h"
#include "timezone.h"
#include "st25dv.h"
#include <time.h>
#include <string.h>
#include <stdio.h>

// Debug flags - set to 1 to enable
#define DEBUG_MESSAGES 0        // Show all special messages on boot
#define DEBUG_FAST_REFRESH 0    // Continuous fast refresh every 15s to test ghosting
#define DEBUG_FRAME_TEST 0      // Show 10 test frames (10s each) for verification

// =============================================================================
// Pin definitions (Rev B)
// =============================================================================

// LEDs
#define LED1_PIN    GPIO_PIN_2
#define LED1_PORT   GPIOD
#define LED2_PIN    GPIO_PIN_11
#define LED2_PORT   GPIOC

// Wakeup (PA0) - OR'd signal from:
// - DS3231 INT (active low) -> P-FET inverter -> HIGH when alarm
// - ST25DV GPO (CMOS) -> HIGH when RF field detected
// Both go through OR diodes to PA0 (pulled low)
#define WAKEUP_PIN  GPIO_PIN_0   // PA0 - Combined wakeup signal
#define WAKEUP_PORT GPIOA

// Power gates (active LOW - P-FET)
#define RTC_PWR     GPIO_PIN_1   // PA1 - DS3231 VCC gate
#define NFC_LPD     GPIO_PIN_2   // PA2 - ST25DV LPD (HIGH=sleep, LOW=active)
#define EPD_PWR     GPIO_PIN_3   // PA3 - Display VCC gate
#define EXT_PWR     GPIO_PIN_9   // PB9 - External 3V3 output gate (active LOW)
#define EXT_PWR_PORT GPIOB

// Battery and debug
#define VBAT_PIN    GPIO_PIN_0   // PB0 - Battery voltage (ADC1_IN8)
#define VBAT_PORT   GPIOB

// ST-Link debug pin exposed on Rev B
#define DEBUG_PIN   GPIO_PIN_3   // PB3 - SWO (optional debug output)

// Battery thresholds (2x AA in series)
// ADC reads 0-4095 for 0-3.3V (assuming direct connection, no divider)
// Fresh: ~3.2V, Empty: ~2.0V
#define VBAT_FULL_MV     3200    // Fresh batteries (2x 1.6V)
#define VBAT_EMPTY_MV    2000    // Dead batteries (2x 1.0V)
#define VBAT_CRITICAL_MV 2200    // Show "change batteries" warning

// DS3231 registers
#define DS3231_ADDR         0x68
#define DS3231_REG_CONTROL  0x0E
#define DS3231_REG_STATUS   0x0F
#define DS3231_REG_ALARM1   0x07  // Alarm 1 seconds register

// I2C for DS3231
static I2C_HandleTypeDef hi2c;

// ADC for battery voltage
static ADC_HandleTypeDef hadc;

// Forward declarations
void SystemClock_Config(void);
void GPIO_Init(void);
void I2C_Init(void);
time64_t ds3231_read_time(void);
void ds3231_set_time(int year, int month, int day, int hour, int min, int sec);
int ds3231_check_and_clear_alarm(void);
void ds3231_set_alarm_minutes(int minutes_ahead);
void enter_standby_mode(void);
void enter_stop_mode_wait_display(void);

// Special date messages lookup table
typedef struct {
    int month;
    int day;
    const char *message;
} DateMessage;

static const DateMessage special_dates[] = {
    // Holidays
    {1, 1, "Happy New Year!"},
    {2, 14, "Happy Valentine's!"},
    {10, 31, "Happy Halloween!"},
    {12, 24, "Merry Christmas!"},
    {12, 31, "Happy New Year!"},
    // Seasons
    {3, 1, "Spring is here!"},
    {6, 1, "Hello Summer"},
    {9, 1, "Autumn begins"},
    {12, 1, "Winter is here"},
    // Fun
    {3, 14, "3.1415926535897.."},
    // Meteor showers (peak nights)
    {1, 3, "Quadrantids tonight"},
    {1, 4, "Quadrantids tonight"},
    {4, 22, "Lyrids tonight"},
    {8, 11, "Perseids tonight"},
    {8, 12, "Perseids tonight"},
    {8, 13, "Perseids tonight"},
    {10, 21, "Orionids tonight"},
    {11, 17, "Leonids tonight"},
    {12, 13, "Geminids tonight"},
    {12, 14, "Geminids tonight"},
    {12, 15, "Geminids tonight"},
    {0, 0, NULL}  // End marker
};

// May 1st rotating messages - cycles each year
static const char* may_day_messages[] = {
    "Power to the people",
    "Solidarity forever",
    "Workers unite",
    "Seize the means",
    "Organize, agitate",
    "Unite and fight",
    "International unity",
    NULL  // End marker
};

// Eclipse dates visible from UK/Margate (2025-2125)
// Stored as packed value: year * 10000 + month * 100 + day
typedef struct {
    int date;  // YYYYMMDD format
    const char *message;
} EclipseDate;

static const EclipseDate eclipse_dates[] = {
    // 2020s
    {20251207, "Lunar Eclipse"},
    {20260812, "Solar Eclipse"},
    {20281231, "Lunar Eclipse"},
    {20290626, "Lunar Eclipse"},
    {20291220, "Lunar Eclipse"},
    // 2030s
    {20321018, "Lunar Eclipse"},
    {20330414, "Lunar Eclipse"},
    // 2040s
    {20430325, "Lunar Eclipse"},
    {20430919, "Lunar Eclipse"},
    {20440313, "Lunar Eclipse"},
    {20440907, "Lunar Eclipse"},
    {20470112, "Lunar Eclipse"},
    {20470707, "Lunar Eclipse"},
    {20480101, "Lunar Eclipse"},
    // 2050s
    {20500506, "Lunar Eclipse"},
    {20500514, "Solar Eclipse"},
    {20501030, "Lunar Eclipse"},
    {20510426, "Lunar Eclipse"},
    {20511019, "Lunar Eclipse"},
    {20540222, "Lunar Eclipse"},
    {20540818, "Lunar Eclipse"},
    {20550211, "Lunar Eclipse"},
    {20580606, "Lunar Eclipse"},
    {20581130, "Lunar Eclipse"},
    {20591105, "Solar Eclipse"},
    // 2060s
    {20610404, "Lunar Eclipse"},
    {20610929, "Lunar Eclipse"},
    {20620325, "Lunar Eclipse"},
    {20620918, "Lunar Eclipse"},
    {20650122, "Lunar Eclipse"},
    {20650205, "Solar Eclipse"},
    {20650717, "Lunar Eclipse"},
    {20660111, "Lunar Eclipse"},
    {20681109, "Lunar Eclipse"},
    {20690506, "Lunar Eclipse"},
    {20691030, "Lunar Eclipse"},
    // 2070s
    {20720304, "Lunar Eclipse"},
    {20720828, "Lunar Eclipse"},
    {20720912, "Solar Eclipse"},
    {20730222, "Lunar Eclipse"},
    {20730817, "Lunar Eclipse"},
    {20750713, "Solar Eclipse"},
    {20760617, "Lunar Eclipse"},
    {20761210, "Lunar Eclipse"},
    {20780511, "Solar Eclipse"},
    {20790501, "Solar Eclipse"},
    {20791010, "Lunar Eclipse"},
    // 2080s
    {20800404, "Lunar Eclipse"},
    {20800913, "Solar Eclipse"},
    {20800929, "Lunar Eclipse"},
    {20810903, "Solar Eclipse"},
    {20820227, "Solar Eclipse"},
    {20830203, "Lunar Eclipse"},
    {20830729, "Lunar Eclipse"},
    {20840123, "Lunar Eclipse"},
    {20870518, "Lunar Eclipse"},
    {20871110, "Lunar Eclipse"},
    {20880421, "Solar Eclipse"},
    // 2090s
    {20900316, "Lunar Eclipse"},
    {20900923, "Solar Eclipse"},
    {20910306, "Lunar Eclipse"},
    {20910829, "Lunar Eclipse"},
    {20920207, "Solar Eclipse"},
    {20930723, "Solar Eclipse"},
    {20940628, "Lunar Eclipse"},
    {20970511, "Solar Eclipse"},
    {20971021, "Lunar Eclipse"},
    {20980416, "Lunar Eclipse"},
    {20981010, "Lunar Eclipse"},
    {20990914, "Solar Eclipse"},
    // 2100s
    {21000904, "Solar Eclipse"},
    {21010214, "Lunar Eclipse"},
    {21010228, "Solar Eclipse"},
    {21010809, "Lunar Eclipse"},
    {21020203, "Lunar Eclipse"},
    {21020730, "Lunar Eclipse"},
    {21050528, "Lunar Eclipse"},
    {21051121, "Lunar Eclipse"},
    {21060503, "Solar Eclipse"},
    {21080327, "Lunar Eclipse"},
    {21090317, "Lunar Eclipse"},
    {21090909, "Lunar Eclipse"},
    // 2110s
    {21120709, "Lunar Eclipse"},
    {21130102, "Lunar Eclipse"},
    {21160427, "Lunar Eclipse"},
    {21161021, "Lunar Eclipse"},
    {21190311, "Solar Eclipse"},
    // 2120s
    {21200214, "Lunar Eclipse"},
    {21200809, "Lunar Eclipse"},
    {21230609, "Lunar Eclipse"},
    {21231203, "Lunar Eclipse"},
    {21260407, "Lunar Eclipse"},
    {0, NULL}  // End marker
};

// Check if date matches an eclipse
static const char* get_eclipse_message(int year, int month, int day) {
    int date = year * 10000 + month * 100 + day;
    for (int i = 0; eclipse_dates[i].message != NULL; i++) {
        if (eclipse_dates[i].date == date) {
            return eclipse_dates[i].message;
        }
    }
    return NULL;
}

// Get special message for a date, or NULL if none
static const char* get_special_message(int year, int month, int day) {
    // May 1st - rotate through messages based on year
    if (month == 5 && day == 1) {
        int count = 0;
        while (may_day_messages[count] != NULL) count++;
        return may_day_messages[year % count];
    }

    // Check for eclipse
    const char* eclipse_msg = get_eclipse_message(year, month, day);
    if (eclipse_msg != NULL) {
        return eclipse_msg;
    }

    // Regular lookup
    for (int i = 0; special_dates[i].message != NULL; i++) {
        if (special_dates[i].month == month && special_dates[i].day == day) {
            return special_dates[i].message;
        }
    }
    return NULL;
}

// Calculate equinox/solstice dates for a given year
// Uses Meeus algorithm - accurate to within a few minutes
// event: 0=Spring Equinox, 1=Summer Solstice, 2=Autumn Equinox, 3=Winter Solstice
static void get_solstice_equinox(int year, int event, int *month, int *day) {
    // Mean Julian Day for events at year 2000
    // From Jean Meeus "Astronomical Algorithms"
    double Y = (year - 2000) / 1000.0;
    double JDE0;

    switch (event) {
        case 0:  // Spring Equinox (March)
            JDE0 = 2451623.80984 + 365242.37404 * Y + 0.05169 * Y * Y
                   - 0.00411 * Y * Y * Y - 0.00057 * Y * Y * Y * Y;
            break;
        case 1:  // Summer Solstice (June)
            JDE0 = 2451716.56767 + 365241.62603 * Y + 0.00325 * Y * Y
                   + 0.00888 * Y * Y * Y - 0.00030 * Y * Y * Y * Y;
            break;
        case 2:  // Autumn Equinox (September)
            JDE0 = 2451810.21715 + 365242.01767 * Y - 0.11575 * Y * Y
                   + 0.00337 * Y * Y * Y + 0.00078 * Y * Y * Y * Y;
            break;
        case 3:  // Winter Solstice (December)
        default:
            JDE0 = 2451900.05952 + 365242.74049 * Y - 0.06223 * Y * Y
                   - 0.00823 * Y * Y * Y + 0.00032 * Y * Y * Y * Y;
            break;
    }

    // Convert Julian Day to calendar date
    // Add 0.5 to get to noon, then truncate
    int Z = (int)(JDE0 + 0.5);
    int A;
    if (Z < 2299161) {
        A = Z;
    } else {
        int alpha = (int)((Z - 1867216.25) / 36524.25);
        A = Z + 1 + alpha - alpha / 4;
    }
    int B = A + 1524;
    int C = (int)((B - 122.1) / 365.25);
    int D = (int)(365.25 * C);
    int E = (int)((B - D) / 30.6001);

    *day = B - D - (int)(30.6001 * E);
    if (E < 14) {
        *month = E - 1;
    } else {
        *month = E - 13;
    }
}

// Check if date is a solstice or equinox, return message or NULL
static const char* get_solar_event_message(int year, int month, int day) {
    int event_month, event_day;

    // Check Spring Equinox
    get_solstice_equinox(year, 0, &event_month, &event_day);
    if (month == event_month && day == event_day) {
        return "Spring Equinox";
    }

    // Check Summer Solstice
    get_solstice_equinox(year, 1, &event_month, &event_day);
    if (month == event_month && day == event_day) {
        return "Summer Solstice";
    }

    // Check Autumn Equinox
    get_solstice_equinox(year, 2, &event_month, &event_day);
    if (month == event_month && day == event_day) {
        return "Autumn Equinox";
    }

    // Check Winter Solstice
    get_solstice_equinox(year, 3, &event_month, &event_day);
    if (month == event_month && day == event_day) {
        return "Winter Solstice";
    }

    return NULL;
}

void SystemClock_Config(void) {
    RCC_OscInitTypeDef osc = {0};
    RCC_ClkInitTypeDef clk = {0};

    __HAL_RCC_PWR_CLK_ENABLE();
    __HAL_PWR_VOLTAGESCALING_CONFIG(PWR_REGULATOR_VOLTAGE_SCALE1);

    // Use HSI (internal 16MHz)
    osc.OscillatorType = RCC_OSCILLATORTYPE_HSI;
    osc.HSIState = RCC_HSI_ON;
    osc.HSICalibrationValue = RCC_HSICALIBRATION_DEFAULT;
    osc.PLL.PLLState = RCC_PLL_ON;
    osc.PLL.PLLSource = RCC_PLLSOURCE_HSI;
    osc.PLL.PLLM = 8;
    osc.PLL.PLLN = 100;
    osc.PLL.PLLP = RCC_PLLP_DIV2;
    osc.PLL.PLLQ = 4;
    HAL_RCC_OscConfig(&osc);

    clk.ClockType = RCC_CLOCKTYPE_HCLK | RCC_CLOCKTYPE_SYSCLK |
                    RCC_CLOCKTYPE_PCLK1 | RCC_CLOCKTYPE_PCLK2;
    clk.SYSCLKSource = RCC_SYSCLKSOURCE_PLLCLK;
    clk.AHBCLKDivider = RCC_SYSCLK_DIV1;
    clk.APB1CLKDivider = RCC_HCLK_DIV2;
    clk.APB2CLKDivider = RCC_HCLK_DIV1;
    HAL_RCC_ClockConfig(&clk, FLASH_LATENCY_3);
}
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
int main(void) {
    HAL_Init();
    SystemClock_Config();
    GPIO_Init();

    // LED1 on briefly to show we're awake
    HAL_GPIO_WritePin(LED1_PORT, LED1_PIN, GPIO_PIN_SET);

    // Power on RTC (always on for alarm functionality)
    HAL_GPIO_WritePin(GPIOA, RTC_PWR, GPIO_PIN_RESET);
    HAL_Delay(10);

    // Initialize I2C
    I2C_Init();

    // Initialize ADC for battery monitoring
    ADC_Init();

    // Check if RTC is present
    if (HAL_I2C_IsDeviceReady(&hi2c, DS3231_ADDR << 1, 2, 100) != HAL_OK) {
        // RTC not found - blink LED1 as error
        while (1) {
            HAL_GPIO_TogglePin(LED1_PORT, LED1_PIN);
            HAL_Delay(200);
        }
    }

    // Check alarm flag - if not set, this is first boot after programming
    int alarm_was_set = ds3231_check_and_clear_alarm();

    // Track if display is already initialized and if time was manually set
    int display_initialized = 0;
    int time_was_set = 0;  // Show datetime after manual time set

    // On first boot (no alarm flag), check for time-set mode
    if (!alarm_was_set) {
        // Power on display early for time-set mode
        HAL_GPIO_WritePin(GPIOA, EPD_PWR, GPIO_PIN_RESET);
        HAL_Delay(10);
        display_set_fontset(FONTSET_HELVETICA);
        display_init_with_rotation(ROTATION_270);
        display_initialized = 1;

        // Check debug flags
        if (DEBUG_FRAME_TEST) {
            run_frame_test();
            while (1) { HAL_Delay(1000); }
        }

        if (DEBUG_MESSAGES) {
            run_message_debug();
            while (1) { HAL_Delay(1000); }
        }

        if (DEBUG_FAST_REFRESH) {
            // Continuous fast refresh test - cycles every 15 seconds
            // Shows cycle count so you can track ghosting buildup
            int cycle = 0;
            time64_t test_time = ds3231_read_time();

            while (1) {
                // Show cycle count as message
                static char cycle_msg[20];
                snprintf(cycle_msg, sizeof(cycle_msg), "Cycle %d", cycle);

                display_clear();
                render_tide_display(test_time, cycle_msg);

                // First cycle uses full refresh, rest use fast
                if (cycle == 0) {
                    display_set_full_mode();
                } else {
                    display_set_fast_full_mode();
                }
                display_update(NULL);
                display_wait_ready();

                // Blink LED to show cycle complete
                HAL_GPIO_WritePin(LED1_PORT, LED1_PIN, GPIO_PIN_SET);
                HAL_Delay(100);
                HAL_GPIO_WritePin(LED1_PORT, LED1_PIN, GPIO_PIN_RESET);

                HAL_Delay(15000);  // Wait 15 seconds

                cycle++;
                test_time += 900;  // Add 15 min each cycle for varied display
            }
        }

        // Show prompt to enter time-set mode
        display_clear();
        display_draw_text(5, 40, "SET TIME?", FONT_MEDIUM);
        display_draw_text(5, 65, "Hold button 2s", FONT_SMALL);
        display_draw_text(5, 90, "Wait 5s to skip", FONT_SMALL);
        display_set_full_mode();  // Full refresh at boot to clear any ghosting
        display_update(NULL);
        display_wait_ready();

        // Wait up to 5 seconds for user to hold button
        uint32_t start = HAL_GetTick();
        int enter_timeset = 0;

        while ((HAL_GetTick() - start) < 5000) {
            if (button_pressed()) {
                // LED on to show button detected
                HAL_GPIO_WritePin(LED1_PORT, LED1_PIN, GPIO_PIN_SET);

                if (button_held_for(2000)) {
                    enter_timeset = 1;
                    wait_button_release();
                    break;
                }
            } else {
                HAL_GPIO_WritePin(LED1_PORT, LED1_PIN, GPIO_PIN_RESET);
            }
            HAL_Delay(10);
        }

        if (enter_timeset) {
            run_timeset_mode();
            time_was_set = 1;  // Show datetime on first refresh after manual time set
        } else {
            // No time-set, use compile time as default
            // Convert from Zurich time (CET/CEST) to Margate time (GMT/BST)
            int year, month, day, hour, min, sec;
            parse_compile_time(&year, &month, &day, &hour, &min, &sec);
            // Subtract 1 hour for Zurich -> Margate conversion
            hour -= 1;
            if (hour < 0) {
                hour = 23;
                day -= 1;
                if (day < 1) {
                    month -= 1;
                    if (month < 1) {
                        month = 12;
                        year -= 1;
                    }
                    const int days_in_month[] = {31,28,31,30,31,30,31,31,30,31,30,31};
                    day = days_in_month[month - 1];
                }
            }
            ds3231_set_time(year, month, day, hour, min, sec);
        }

        // === First boot info screen ===
        // Show date/time and battery on one screen for 4 seconds
        time64_t boot_time = ds3231_read_time();
        struct tm *boot_local = utc_to_margate(boot_time);
        uint32_t mv = read_battery_mv();
        int percent = get_battery_percent();

        display_clear();
        char date_str[32], time_str[16], batt_str[16];
        snprintf(date_str, sizeof(date_str), "%02d/%02d/%04d",
                 boot_local->tm_mday, boot_local->tm_mon + 1, boot_local->tm_year + 1900);
        snprintf(time_str, sizeof(time_str), "%02d:%02d",
                 boot_local->tm_hour, boot_local->tm_min);
        snprintf(batt_str, sizeof(batt_str), "%ld.%02ldV  %d%%", mv / 1000, (mv % 1000) / 10, percent);

        int date_w = display_get_text_width(date_str, FONT_LARGE);
        int time_w = display_get_text_width(time_str, FONT_LARGE);
        int batt_w = display_get_text_width(batt_str, FONT_MEDIUM);

        display_draw_text((DISPLAY_WIDTH - date_w) / 2, 45, date_str, FONT_LARGE);
        display_draw_text((DISPLAY_WIDTH - time_w) / 2, 75, time_str, FONT_LARGE);
        display_draw_text((DISPLAY_WIDTH - batt_w) / 2, 105, batt_str, FONT_MEDIUM);
        // Use fast full refresh for all updates (single flash, ~1s)
        display_set_fast_full_mode();

        display_update(NULL);
        display_wait_ready();
        HAL_Delay(3000);  // Brief pause before normal operation
    }

    // Read time from RTC
    time64_t current_time = ds3231_read_time();

    // Power on and initialize display (if not already done in time-set mode)
    if (!display_initialized) {
        HAL_GPIO_WritePin(GPIOA, EPD_PWR, GPIO_PIN_RESET);
        HAL_Delay(10);
        display_set_fontset(FONTSET_HELVETICA);
        display_init_with_rotation(ROTATION_270);
    }

    // Determine message for display
    struct tm *local = utc_to_margate(current_time);
    const char *message = NULL;

    // Check battery status first - highest priority warning
    if (is_battery_critical()) {
        message = "Change batteries";
    } else if (time_was_set) {
        // After manual time set, show datetime so user can verify
        static char datetime_str[32];
        snprintf(datetime_str, sizeof(datetime_str), "%02d/%02d/%04d %02d:%02d",
                 local->tm_mday, local->tm_mon + 1, local->tm_year + 1900,
                 local->tm_hour, local->tm_min);
        message = datetime_str;
    } else {
        // Check for special date message (holidays override solar events)
        message = get_special_message(local->tm_year + 1900, local->tm_mon + 1, local->tm_mday);

        // If no special date, check for solar events (equinox/solstice)
        if (message == NULL) {
            message = get_solar_event_message(local->tm_year + 1900,
                                              local->tm_mon + 1,
                                              local->tm_mday);
        }
    }

    // Daily full refresh at 3am to clear any accumulated ghosting
    // Fast refresh for all other updates
    if (local->tm_hour == 3 && local->tm_min == 0) {
        display_set_full_mode();  // Full OTP refresh clears ghosting
    } else {
        display_set_fast_full_mode();  // Fast refresh (~1s single flash)
    }

    // Render tide display (after setting refresh mode)
    display_clear();
    render_tide_display(current_time, message);

    // Send buffer to display (starts refresh)
    display_update(NULL);

    // Set next alarm based on time of day (15/20/60 min intervals)
    ds3231_set_alarm_next_interval(current_time);

    // LEDs off before sleep
    HAL_GPIO_WritePin(LED1_PORT, LED1_PIN, GPIO_PIN_RESET);
    HAL_GPIO_WritePin(LED2_PORT, LED2_PIN, GPIO_PIN_RESET);

    // Clear any pending DS3231 alarm flags
    ds3231_check_and_clear_alarm();
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

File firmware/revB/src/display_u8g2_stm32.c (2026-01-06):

/**
 * U8g2 STM32 Display Backend
 *
 * Implements display.h interface using u8g2 library with STM32 HAL SPI.
 * Uses IL3820/SSD1680 driver for 2.9" e-paper display (128x296).
 *
 * Pin mapping (from pinout.txt):
 *   PA3: Display VCC gate (P-FET, LOW=ON)
 *   PA4: CS
 *   PA5: CLK (SPI1_SCK)
 *   PA6: DC
 *   PA7: DIN (SPI1_MOSI)
 *   PA8: RST
 *   PA9: BUSY
 */

#include "display.h"
#include "u8g2.h"
#include "stm32f4xx_hal.h"
#include <string.h>

// SSD1680 setup function (custom driver based on tricolor BWR)
void u8g2_Setup_ssd1680_296x128_f(u8g2_t *u8g2, const u8g2_cb_t *rotation,
                                   u8x8_msg_cb byte_cb, u8x8_msg_cb gpio_and_delay_cb);

// Pin definitions
#define EPD_PWR_PIN    GPIO_PIN_3
#define EPD_CS_PIN     GPIO_PIN_4
#define EPD_CLK_PIN    GPIO_PIN_5
#define EPD_DC_PIN     GPIO_PIN_6
#define EPD_DIN_PIN    GPIO_PIN_7
#define EPD_RST_PIN    GPIO_PIN_8
#define EPD_BUSY_PIN   GPIO_PIN_9
#define EPD_PORT       GPIOA

// Global u8g2 instance
static u8g2_t u8g2;

// SPI handle
static SPI_HandleTypeDef hspi;

// Current settings
static int current_rotation = ROTATION_0;
static int current_fontset = FONTSET_HELVETICA;

// Forward declarations
static uint8_t u8x8_stm32_gpio_and_delay(u8x8_t *u8x8, uint8_t msg, uint8_t arg_int, void *arg_ptr);
static uint8_t u8x8_stm32_byte_hw_spi(u8x8_t *u8x8, uint8_t msg, uint8_t arg_int, void *arg_ptr);

// Initialize SPI peripheral
static void spi_init(void) {
    __HAL_RCC_SPI1_CLK_ENABLE();
    __HAL_RCC_GPIOA_CLK_ENABLE();

    // Configure SPI pins: CLK (PA5), MOSI (PA7)
    GPIO_InitTypeDef gpio = {0};
    gpio.Pin = EPD_CLK_PIN | EPD_DIN_PIN;
    gpio.Mode = GPIO_MODE_AF_PP;
    gpio.Pull = GPIO_NOPULL;
    gpio.Speed = GPIO_SPEED_FREQ_HIGH;
    gpio.Alternate = GPIO_AF5_SPI1;
    HAL_GPIO_Init(GPIOA, &gpio);

    // Configure control pins: CS, DC, RST (outputs), BUSY (input), PWR (output)
    gpio.Pin = EPD_CS_PIN | EPD_DC_PIN | EPD_RST_PIN | EPD_PWR_PIN;
    gpio.Mode = GPIO_MODE_OUTPUT_PP;
    gpio.Pull = GPIO_NOPULL;
    gpio.Speed = GPIO_SPEED_FREQ_LOW;
    HAL_GPIO_Init(GPIOA, &gpio);

    gpio.Pin = EPD_BUSY_PIN;
    gpio.Mode = GPIO_MODE_INPUT;
    gpio.Pull = GPIO_NOPULL;
    HAL_GPIO_Init(GPIOA, &gpio);

    // Power off initially (P-FET, HIGH = OFF)
    HAL_GPIO_WritePin(EPD_PORT, EPD_PWR_PIN, GPIO_PIN_SET);

    // CS high (inactive)
    HAL_GPIO_WritePin(EPD_PORT, EPD_CS_PIN, GPIO_PIN_SET);

    // Configure SPI
    hspi.Instance = SPI1;
    hspi.Init.Mode = SPI_MODE_MASTER;
    hspi.Init.Direction = SPI_DIRECTION_2LINES;
    hspi.Init.DataSize = SPI_DATASIZE_8BIT;
    hspi.Init.CLKPolarity = SPI_POLARITY_LOW;
    hspi.Init.CLKPhase = SPI_PHASE_1EDGE;
    hspi.Init.NSS = SPI_NSS_SOFT;
    hspi.Init.BaudRatePrescaler = SPI_BAUDRATEPRESCALER_8;  // ~2MHz at 16MHz clock
    hspi.Init.FirstBit = SPI_FIRSTBIT_MSB;
    hspi.Init.TIMode = SPI_TIMODE_DISABLE;
    hspi.Init.CRCCalculation = SPI_CRCCALCULATION_DISABLE;
    HAL_SPI_Init(&hspi);
}

// GPIO and delay callback for u8g2
static uint8_t u8x8_stm32_gpio_and_delay(u8x8_t *u8x8, uint8_t msg, uint8_t arg_int, void *arg_ptr) {
    switch (msg) {
        case U8X8_MSG_GPIO_AND_DELAY_INIT:
            // Already done in spi_init()
            break;

        case U8X8_MSG_DELAY_MILLI:
            HAL_Delay(arg_int);
            break;

        case U8X8_MSG_DELAY_10MICRO:
        case U8X8_MSG_DELAY_100NANO:
            // Short delays - just a few NOPs
            for (volatile int i = 0; i < arg_int * 10; i++) { __NOP(); }
            break;

        case U8X8_MSG_GPIO_CS:
            HAL_GPIO_WritePin(EPD_PORT, EPD_CS_PIN, arg_int ? GPIO_PIN_SET : GPIO_PIN_RESET);
            break;

        case U8X8_MSG_GPIO_DC:
            HAL_GPIO_WritePin(EPD_PORT, EPD_DC_PIN, arg_int ? GPIO_PIN_SET : GPIO_PIN_RESET);
            break;

        case U8X8_MSG_GPIO_RESET:
            HAL_GPIO_WritePin(EPD_PORT, EPD_RST_PIN, arg_int ? GPIO_PIN_SET : GPIO_PIN_RESET);
            break;

        case U8X8_MSG_GPIO_E:
            // E-paper busy pin - return busy state
            // Note: Most e-paper displays are HIGH when busy
            break;

        default:
            return 0;
    }
    return 1;
}

// Hardware SPI byte callback for u8g2
static uint8_t u8x8_stm32_byte_hw_spi(u8x8_t *u8x8, uint8_t msg, uint8_t arg_int, void *arg_ptr) {
    switch (msg) {
        case U8X8_MSG_BYTE_SEND:
            HAL_SPI_Transmit(&hspi, (uint8_t *)arg_ptr, arg_int, 1000);
            break;

        case U8X8_MSG_BYTE_INIT:
            // SPI already initialized
            break;

        case U8X8_MSG_BYTE_SET_DC:
            HAL_GPIO_WritePin(EPD_PORT, EPD_DC_PIN, arg_int ? GPIO_PIN_SET : GPIO_PIN_RESET);
            break;

        case U8X8_MSG_BYTE_START_TRANSFER:
            HAL_GPIO_WritePin(EPD_PORT, EPD_CS_PIN, GPIO_PIN_RESET);
            break;

        case U8X8_MSG_BYTE_END_TRANSFER:
            HAL_GPIO_WritePin(EPD_PORT, EPD_CS_PIN, GPIO_PIN_SET);
            break;

        default:
            return 0;
    }
    return 1;
}

void display_set_fontset(int fontset) {
    current_fontset = fontset;
}

void display_init_with_rotation(int rotation) {
    current_rotation = rotation;

    // Initialize SPI and GPIO
    spi_init();

    // Power on display (P-FET, LOW = ON)
    HAL_GPIO_WritePin(EPD_PORT, EPD_PWR_PIN, GPIO_PIN_RESET);
    HAL_Delay(100);

    // Select rotation
    const u8g2_cb_t *cb;
    switch (rotation) {
        case ROTATION_90:  cb = U8G2_R1; break;
        case ROTATION_180: cb = U8G2_R2; break;
        case ROTATION_270: cb = U8G2_R3; break;
        default:           cb = U8G2_R0; break;
    }

    // Setup u8g2 with SSD1680 driver
    u8g2_Setup_ssd1680_296x128_f(&u8g2, cb, u8x8_stm32_byte_hw_spi, u8x8_stm32_gpio_and_delay);

    // Initialize display
    u8g2_InitDisplay(&u8g2);
    u8g2_SetPowerSave(&u8g2, 0);

    display_clear();
}

void display_init(void) {
    display_init_with_rotation(ROTATION_0);
}

void display_clear(void) {
    u8g2_ClearBuffer(&u8g2);
}

void display_draw_pixel(int x, int y, uint8_t color) {
    u8g2_SetDrawColor(&u8g2, color == COLOR_BLACK ? 1 : 0);
    u8g2_DrawPixel(&u8g2, x, y);
}
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

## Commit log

2026-01-06 Initial commit - Tidal Clock for Margate, UK
    Low-power e-paper display showing tide times, moon phases, and astronomical
    information. Designed for multi-year battery life with 15-minute update cycles.
    Features:
    - 31-constituent harmonic tide model (~5 min accuracy)
    - Moon phase with Meeus algorithm
    - Sunrise/sunset with NOAA algorithm
    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
    [BOM-gift.csv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]
2026-01-07 changed folder structure
    [board.dxf, clock.dxf, clock_2.dxf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]
2026-01-07 split big file
    [margate_minute_2019.csv, margate_minute_2020.csv, margate_minute_2021.csv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]
2026-01-07 Added location suppoer including NOAA API
    [margate_hwlw_2010-2040.csv, margate_minute_2019.csv, margate_minute_2020.csv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]
